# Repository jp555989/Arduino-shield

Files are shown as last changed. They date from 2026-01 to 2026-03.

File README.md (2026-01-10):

# Arduino-shield
This is a project I made for my engineer thesis which involves designing a shield for Arduino with as many useful functions as possible, using ready to program modules like LCD Display, RTC module, etc.

I used KiCad for designing the PCB and LtSpice for the simulation of electronic circuits, simulations involved op-amp in voltage phase inverting configuration, buffer and resistor ladder with Monte Carlo Method.

Presented files have updated version of PCB with important fixes, the board presented on photos is the older version.







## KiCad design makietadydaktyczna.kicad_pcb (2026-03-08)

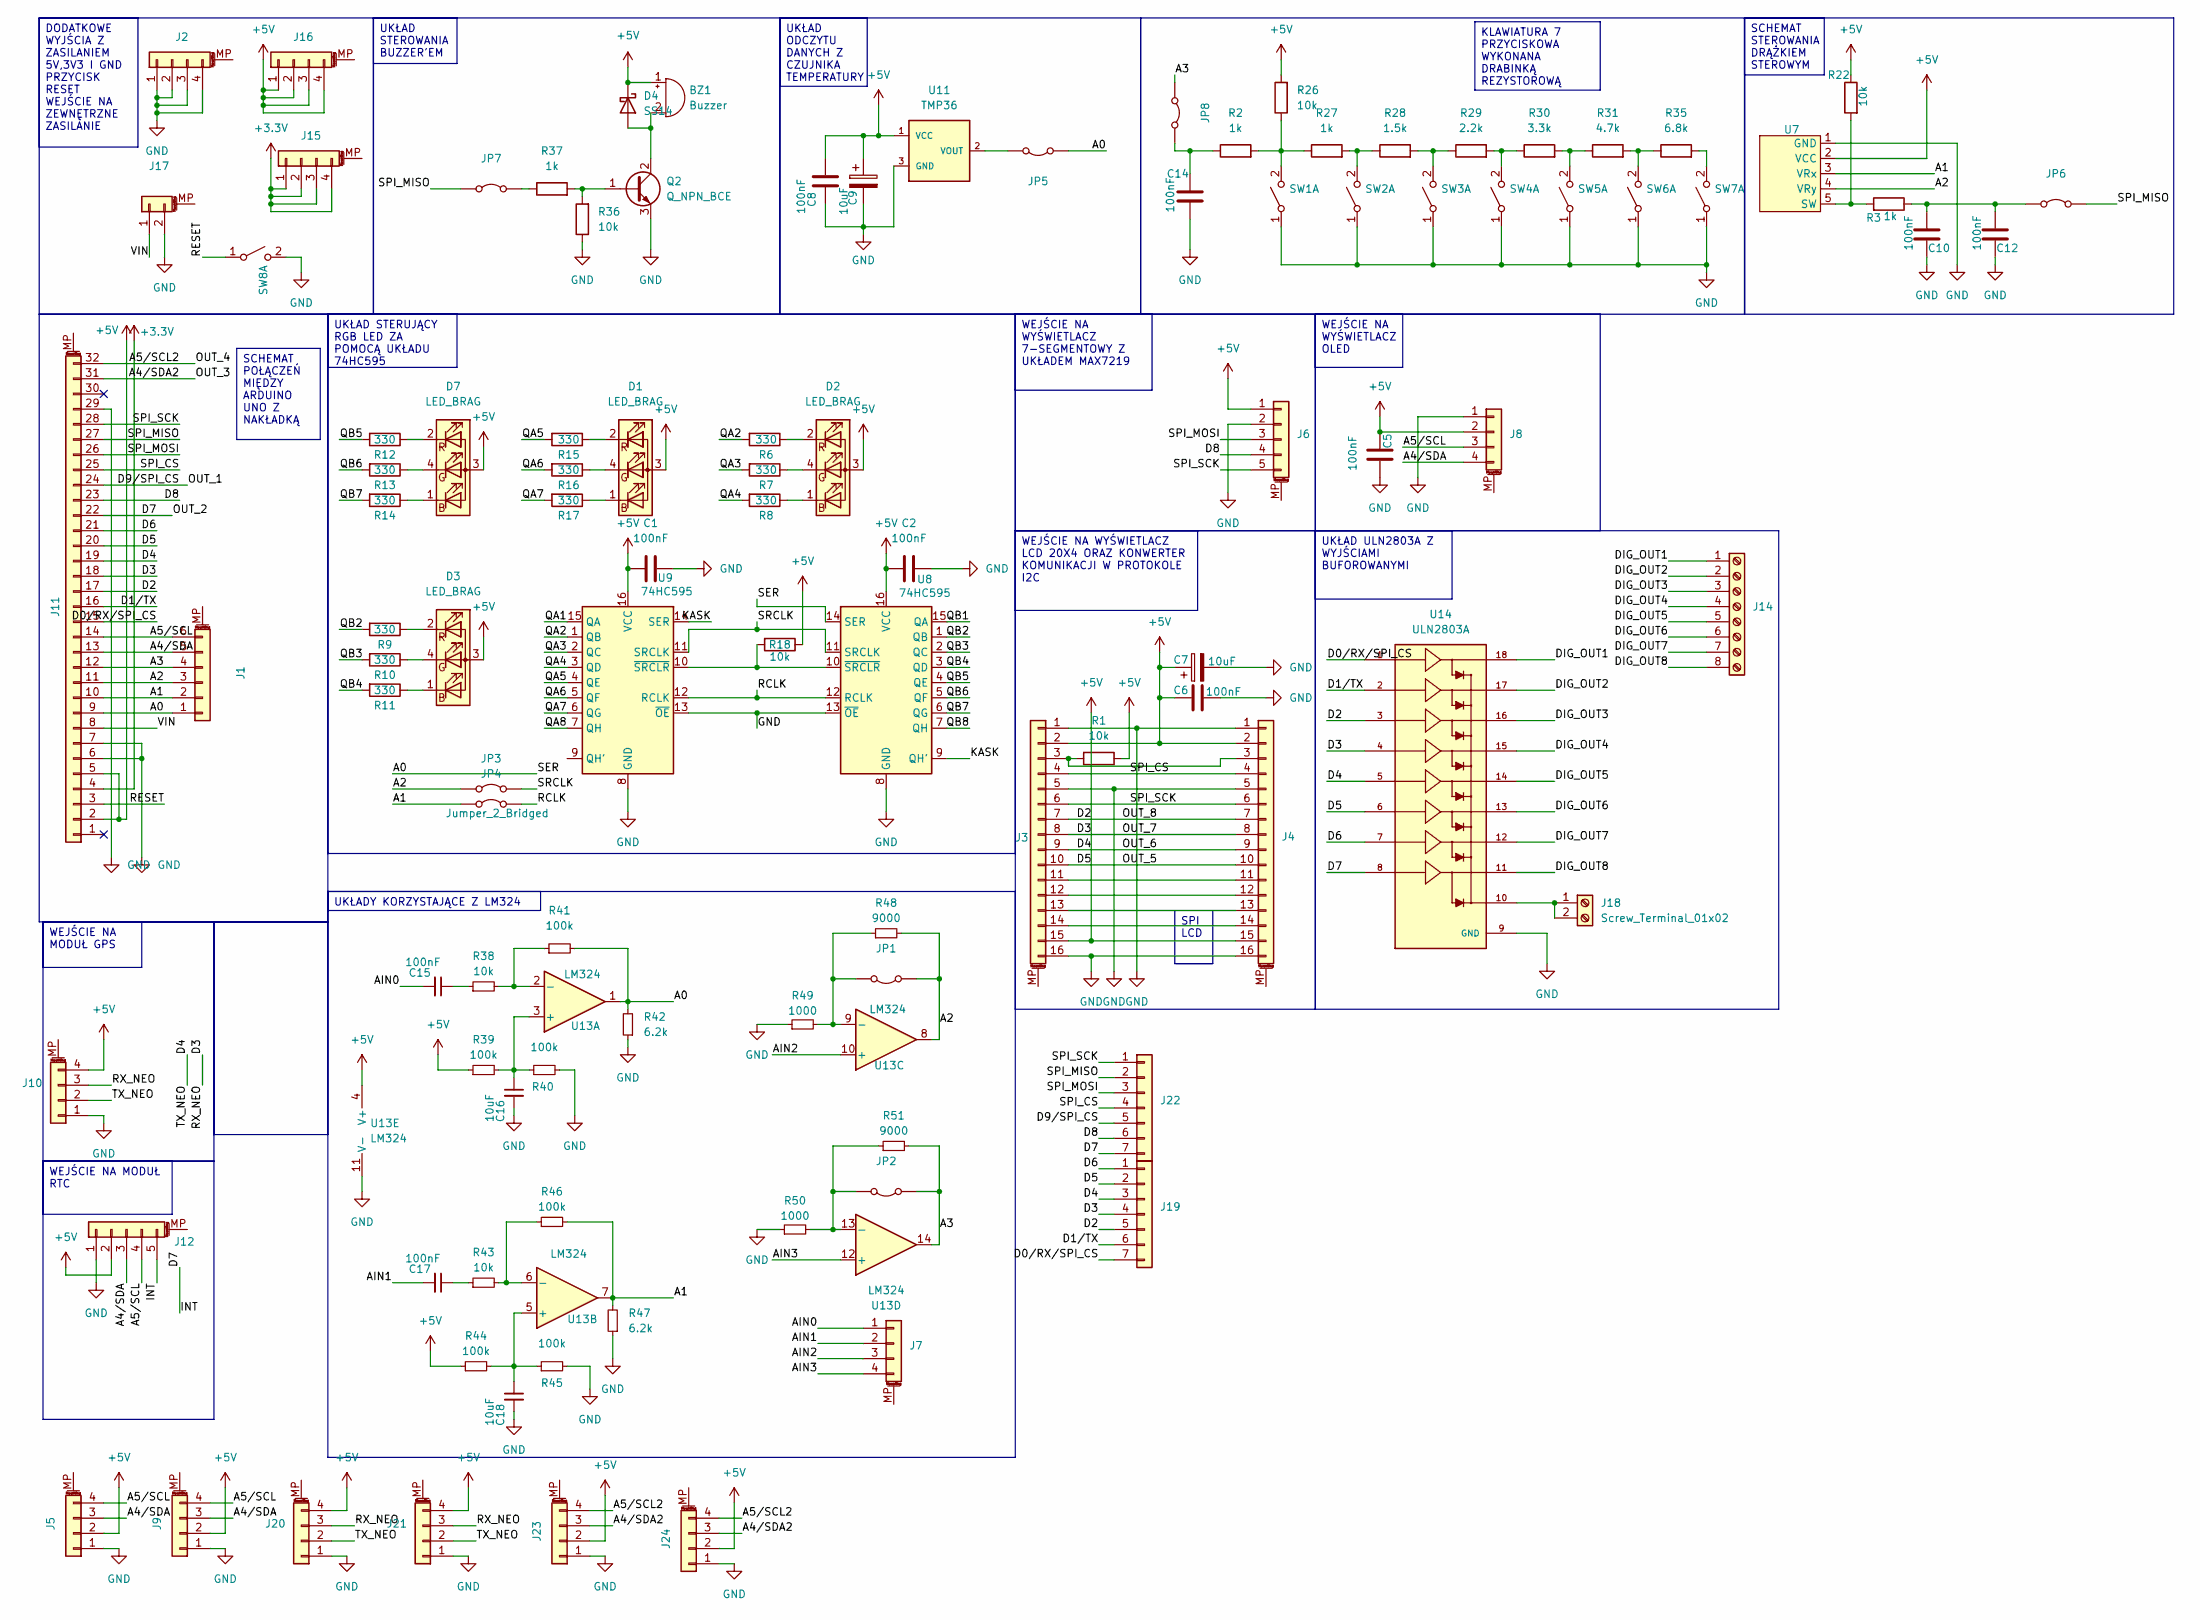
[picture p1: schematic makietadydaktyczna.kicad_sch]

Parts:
BZ1: Buzzer; Buzzer_D14mm_H7mm_P10mm
C1, C2, C5, C6, C8, C10, C12, C14, C15, C17: 100nF; C_0805_2012Metric_Pad1.18x1.45mm_HandSolder
C7, C9: 10uF; C_Radial_D5.0mm_H11.0mm_P2.00mm
C16, C18: 10uF; C_0805_2012Metric_Pad1.18x1.45mm_HandSolder
D1, D2, D3, D7: LED_BRAG; LED_D5.0mm-4_RGB_Wide_Pins
D4: SS14; D_SMA
J1: Conn_01x06_MountingPin; PinSocket_1x06_P2.54mm_Vertical
J2, J5, J8, J9, J10, J15, J16, J20, J21, J23, J24: Conn_01x04_MountingPin; PinSocket_1x04_P2.54mm_Vertical
J3, J4: Conn_01x16_MountingPin; PinSocket_1x16_P2.54mm_Vertical
J6, J12: Conn_01x05_MountingPin; PinSocket_1x05_P2.54mm_Vertical
J7: Conn_01x04_MountingPin; PinHeader_1x04_P2.54mm_Vertical
J11: Conn_01x32_MountingPin; Arduino_UNO_R3
J14: Screw_Terminal_01x08; TerminalBlock_Xinya_XY308-2.54-8P_1x08_P2.54mm_Horizontal
J17: Conn_01x02_MountingPin; PinSocket_1x02_P2.54mm_Vertical
J18: Screw_Terminal_01x02; TerminalBlock_Xinya_XY308-2.54-2P_1x02_P2.54mm_Horizontal
J19, J22: Conn_01x07; PinSocket_1x07_P2.54mm_Vertical
JP1, JP2, JP3, JP4, JP5, JP6, JP7, JP8: Jumper_2_Bridged; PinHeader_1x02_P2.54mm_Vertical
Q2: Q_NPN_BCE; TO-92
R1, R18, R22, R26, R36, R38, R43: 10k; R_0805_2012Metric_Pad1.20x1.40mm_HandSolder
R2, R3, R27, R37: 1k; R_0805_2012Metric_Pad1.20x1.40mm_HandSolder
R6, R7, R8, R9, R10, R11, R12, R13, R14, R15, R16, R17: 330; R_0805_2012Metric_Pad1.20x1.40mm_HandSolder
R28: 1.5k; R_0805_2012Metric_Pad1.20x1.40mm_HandSolder
R29: 2.2k; R_0805_2012Metric_Pad1.20x1.40mm_HandSolder
R30: 3.3k; R_0805_2012Metric_Pad1.20x1.40mm_HandSolder
R31: 4.7k; R_0805_2012Metric_Pad1.20x1.40mm_HandSolder
R35: 6.8k; R_0805_2012Metric_Pad1.20x1.40mm_HandSolder
R39, R40, R41, R44, R45, R46: 100k; R_0805_2012Metric_Pad1.20x1.40mm_HandSolder
R42, R47: 6.2k; R_0805_2012Metric_Pad1.20x1.40mm_HandSolder
R48, R51: 9000; R_0805_2012Metric_Pad1.20x1.40mm_HandSolder
R49, R50: 1000; R_0805_2012Metric_Pad1.20x1.40mm_HandSolder
SW1, SW2, SW3, SW4, SW5, SW6, SW7, SW8: SW_DPST_x2; SW_PUSH_6mm_H5mm
U6: (no value)
U7: PinSocket_1x05_P2.54mm_Vertical
U8, U9: 74HC595; SO16
U11: TMP36; TO-92
U13: LM324; SOIC127P600X175-14N
U14: ULN2803A; SOIC127P1030X265-18N; PARTREV 4

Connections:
+3.3V: J11.4, J15.1, J15.2, J15.3, J15.4
+5V: BZ1.1 (+), C1.1, C2.1, C5.2, C6.1, C7.1, C8.1, C9.1, D1.3 (A), D2.3 (A), D3.3 (A), D4.1 (K), D7.3 (A), J3.2, J3.15, J4.2, J4.15, J5.2, J6.1, J8.2, J9.2, J10.4, J11.2, J11.5, J12.2, J16.1, J16.2, J16.3, J16.4, J20.4, J21.4, J23.2, J24.2, R1.1, R18.1, R22.1, R26.2, R39.1, R44.1, U7.2 (VCC), U8.16 (VCC), U9.16 (VCC), U11.1 (VCC), U13.4 (V+)
/A0: J1.1, J11.9, JP5.1 (A), R41.2, R42.2, U8.14 (SER), U13.1
/A1: J1.2, J11.10, JP4.1 (A), R46.2, R47.2, U7.3 (VRx), U13.7
/A2: J1.3, J11.11, JP1.1 (A), JP3.1 (A), R48.2, U7.4 (VRy), U13.8
/A3: J1.4, J11.12, JP2.1 (A), JP8.1 (A), R51.2, U13.14
/A4/SDA: J1.5, J5.3, J8.4, J9.3, J11.13, J12.3
/A4/SDA2: J11.31, J23.3, J24.3
/A5/SCL: J1.6, J5.4, J8.3, J9.4, J11.14, J12.4
/A5/SCL2: J11.32, J23.4, J24.4
/AIN0: C15.2, J7.1
/AIN1: C17.2, J7.2
/AIN2: J7.3, U13.10 (+)
/AIN3: J7.4, U13.12 (+)
/D0/RX/SPI_CS: J11.15, J19.7, U14.1
/D1/TX: J11.16, J19.6, U14.2
/D2: J3.7, J4.7, J11.17, J19.5, U14.3
/D3: J3.8, J4.8, J10.3, J11.18, J19.4, J20.3, J21.3, U14.4
/D4: J3.9, J4.9, J10.2, J11.19, J19.3, J20.2, J21.2, U14.5
/D5: J3.10, J4.10, J11.20, J19.2, U14.6
/D6: J11.21, J19.1, U14.7
/D7: J11.22, J12.5, J22.7, U14.8
/D8: J6.4, J11.23, J22.6
/D9/SPI_CS: J11.24, J22.5
/DIG_OUT1: J14.1, U14.18
/DIG_OUT2: J14.2, U14.17
/DIG_OUT3: J14.3, U14.16
/DIG_OUT4: J14.4, U14.15
/DIG_OUT5: J14.5, U14.14
/DIG_OUT6: J14.6, U14.13
/DIG_OUT7: J14.7, U14.12
/DIG_OUT8: J14.8, U14.11
/KASK: U8.9 (QH'), U9.14 (SER)
/QA1: U9.15 (QA)
/QA2: R6.2, U9.1 (QB)
/QA3: R7.2, U9.2 (QC)
/QA4: R8.2, U9.3 (QD)
/QA5: R15.2, U9.4 (QE)
/QA6: R16.2, U9.5 (QF)
/QA7: R17.2, U9.6 (QG)
/QA8: U9.7 (QH)
/QB1: U8.15 (QA)
/QB2: R9.2, U8.1 (QB)
/QB3: R10.2, U8.2 (QC)
/QB4: R11.2, U8.3 (QD)
/QB5: R12.2, U8.4 (QE)
/QB6: R13.2, U8.5 (QF)
/QB7: R14.2, U8.6 (QG)
/QB8: U8.7 (QH)
/RCLK: JP4.2 (B), U8.12 (RCLK), U9.12 (RCLK)
/RESET: J11.3, SW8.1 (A); also elsewhere on the board
/SPI_CS: J3.4, J4.4, J11.25, J22.4
/SPI_MISO: J11.27, J22.2, JP6.2 (B), JP7.1 (A)
/SPI_MOSI: J6.3, J11.26, J22.3
/SPI_SCK: J3.6, J4.6, J6.5, J11.28, J22.1
/SRCLK: JP3.2 (B), U8.11 (SRCLK), U9.11 (SRCLK)
/VIN: J11.8, J17.1
GND: C1.2, C2.2, C5.1, C6.2, C7.2, C8.2, C9.2, C10.2, C12.2, C14.1, C16.2, C18.2, J2.1, J2.2, J2.3, J2.4, J3.1, J3.5, J3.16, J4.1, J4.5, J4.16, J5.1, J6.2, J8.1, J9.1, J10.1, J11.6, J11.7, J11.29, J12.1, J17.2, J20.1, J21.1, J23.1, J24.1, Q2.3 (E), R36.1, R40.2, R42.1, R45.2, R47.1, R49.1, R50.1, SW1.1 (A), SW2.1 (A), SW3.1 (A), SW4.1 (A), SW5.1 (A), SW6.1 (A), SW7.1 (A), SW8.2 (B), U7.1 (GND), U8.8 (GND), U8.13 (~OE), U9.8 (GND), U9.13 (~OE), U11.3 (GND), U13.11 (V-), U14.9 (GND); also elsewhere on the board
unnamed: BZ1.2 (-), D4.2 (A), Q2.2 (C)
unnamed: C15.1, R38.1
unnamed: C17.1, R43.1
unnamed: D1.1 (BK), R17.1
unnamed: D1.4 (GK), R16.1
unnamed: D1.2 (RK), R15.1
unnamed: D2.1 (BK), R8.1
unnamed: D2.4 (GK), R7.1
unnamed: D2.2 (RK), R6.1
unnamed: D3.1 (BK), R11.1
unnamed: D3.4 (GK), R10.1
unnamed: D3.2 (RK), R9.1
unnamed: D7.1 (BK), R14.1
unnamed: D7.4 (GK), R13.1
unnamed: D7.2 (RK), R12.1
unnamed: J3.3, J4.3, R1.2
unnamed: J3.11, J4.11
unnamed: J3.12, J4.12
unnamed: J3.13, J4.13
unnamed: J3.14, J4.14
unnamed: J18.1, J18.2, U14.10
unnamed: JP1.2 (B), R48.1, R49.2, U13.9 (-)
unnamed: JP2.2 (B), R50.2, R51.1, U13.13 (-)
unnamed: JP5.2 (B), U11.2 (VOUT)
unnamed: C10.1, C12.1, JP6.1 (A), R3.1
unnamed: JP7.2 (B), R37.1
unnamed: C14.2, JP8.2 (B), R2.1
unnamed: Q2.1 (B), R36.2, R37.2
unnamed: R2.2, R26.1, R27.1, SW1.2 (B)
unnamed: R27.2, R28.1, SW2.2 (B)
unnamed: R28.2, R29.1, SW3.2 (B)
unnamed: R29.2, R30.1, SW4.2 (B)
unnamed: R30.2, R31.1, SW5.2 (B)
unnamed: R31.2, R35.1, SW6.2 (B)
unnamed: R35.2, SW7.2 (B)
unnamed: R3.2, R22.2, U7.5 (SW)
unnamed: R18.2, U8.10 (~SRCLR), U9.10 (~SRCLR)
unnamed: C16.1, R39.2, R40.1, U13.3 (+)
unnamed: R38.2, R41.1, U13.2 (-)
unnamed: C18.1, R44.2, R45.1, U13.5 (+)
unnamed: R43.2, R46.1, U13.6 (-)

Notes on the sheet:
SCHEMAT STEROWANIA DRĄŻKIEM STEROWYM
KLAWIATURA 7 PRZYCISKOWA WYKONANA DRABINKĄ REZYSTOROWĄ
SCHEMAT POŁĄCZEŃ MIĘDZY ARDUINO UNO Z NAKŁADKĄ
WEJŚCIE NA MODUŁ RTC
DODATKOWE WYJŚCIA Z ZASILANIEM 5V,3V3 I GND PRZYCISK RESET WEJŚCIE NA ZEWNĘTRZNE ZASILANIE
WEJŚCIE NA MODUŁ GPS
UKŁADY KORZYSTAJĄCE Z LM324
SPI LCD
WEJŚCIE NA WYŚWIETLACZ 7-SEGMENTOWY Z UKŁADEM MAX7219
UKŁAD ODCZYTU DANYCH Z CZUJNIKA TEMPERATURY
UKŁAD ULN2803A Z WYJŚCIAMI BUFOROWANYMI
WEJŚCIE NA WYŚWIETLACZ LCD 20X4 ORAZ KONWERTER KOMUNIKACJI W PROTOKOLE I2C
UKŁAD STEROWANIA BUZZER'EM
WEJŚCIE NA WYŚWIETLACZ OLED
UKŁAD STERUJĄCY RGB LED ZA POMOCĄ UKŁADU 74HC595

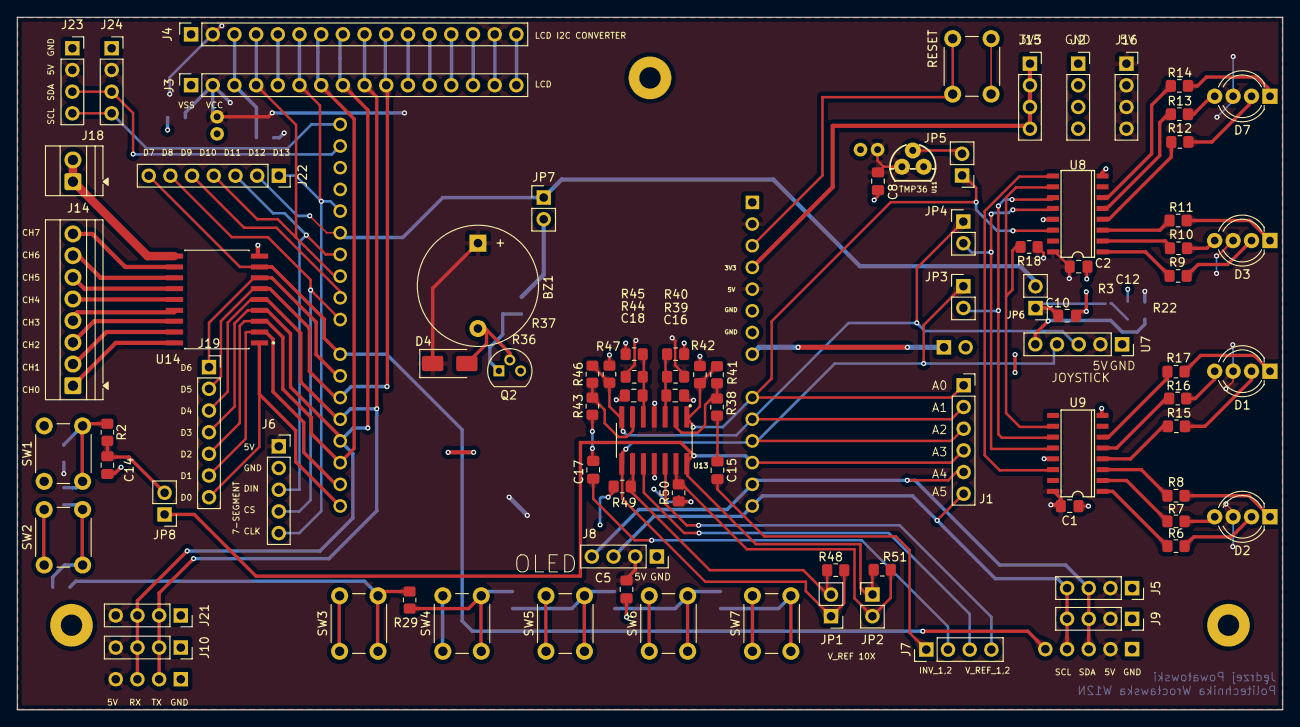
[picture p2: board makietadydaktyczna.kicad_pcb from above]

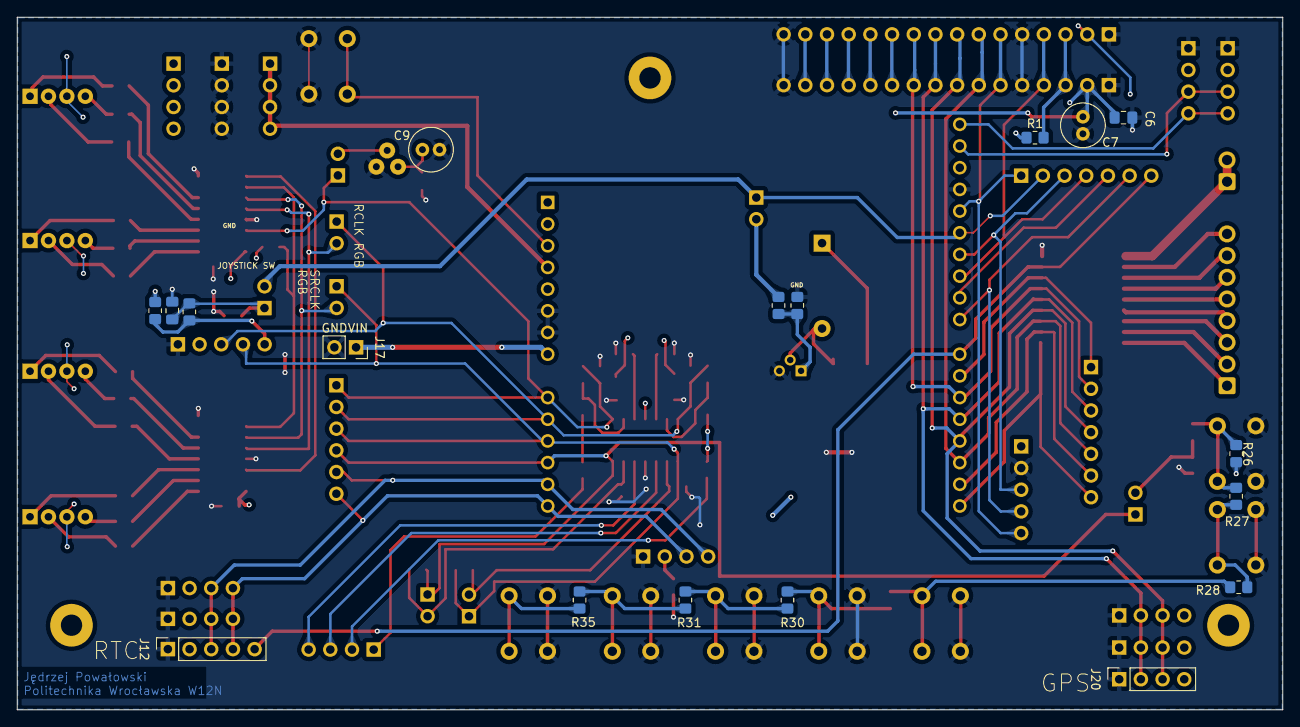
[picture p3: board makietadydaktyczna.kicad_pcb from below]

Board: 2 copper layers, 148.2 x 81.1 mm, 106 parts (18 on the bottom side), 95 nets.

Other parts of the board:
RESET: SW_DPST_x2; SW_PUSH_6mm_H5mm

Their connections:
/RESET: RESET.2 (B); also elsewhere on the board
GND: RESET.1 (A); also elsewhere on the board

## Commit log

2025-12-21 Enhance README with project details and images
    Expanded project description and added details about tools used for PCB design and circuit simulation.
2026-01-10 Updated design
    -Added multiplexed pins for communication protocols (I2C, UART)
    -Fixed problems with ULN2803A COM pin
    -Added multiplexed digital pins
    -Fixed opamp problems involving disconnected ground plane
    -Fixed problem with opamp reading voltage drop from resistor ladder from buttons
    -Increased the size of the board a little
    [makietadydaktyczna.kicad_pcb, makietadydaktyczna.kicad_sch]
2026-01-10 Update README with new PCB version and fixes
    Updated README to reflect the latest PCB version and fixes.
